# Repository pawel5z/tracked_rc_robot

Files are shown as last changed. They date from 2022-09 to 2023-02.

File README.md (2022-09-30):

# tracked_rc_robot

Tracked robot prototype with bluetooth remote control, using [Dabble app](https://thestempedia.com/docs/dabble/game-pad-module/)'s gamepad module.



## Demo

demo_thumbnail (https://youtu.be/WPtYzlPSiFU)

## Components

* [Black Gladiator - Tracked Robot Chassis](https://www.dfrobot.com/product-1860.html)
* Raspberry Pi Pico
* HC-05 bluetooth module
* 2 x L293D motor driver
* L7805 voltage regulator
* tact switch 6x6mm THT
* 2 x capacitor 1µF
* 3 x capacitor 100nF
* capacitor 330nF
* 2 x Li-ion 18650 3.7V 2200mAh cell

## Notes

[Board layout](https://github.com/pawel5z/tracked_rc_robot/blob/main/circuit/stripboard.diy) created with [DIY Layout Creator](http://diy-fever.com/software/diylc/).



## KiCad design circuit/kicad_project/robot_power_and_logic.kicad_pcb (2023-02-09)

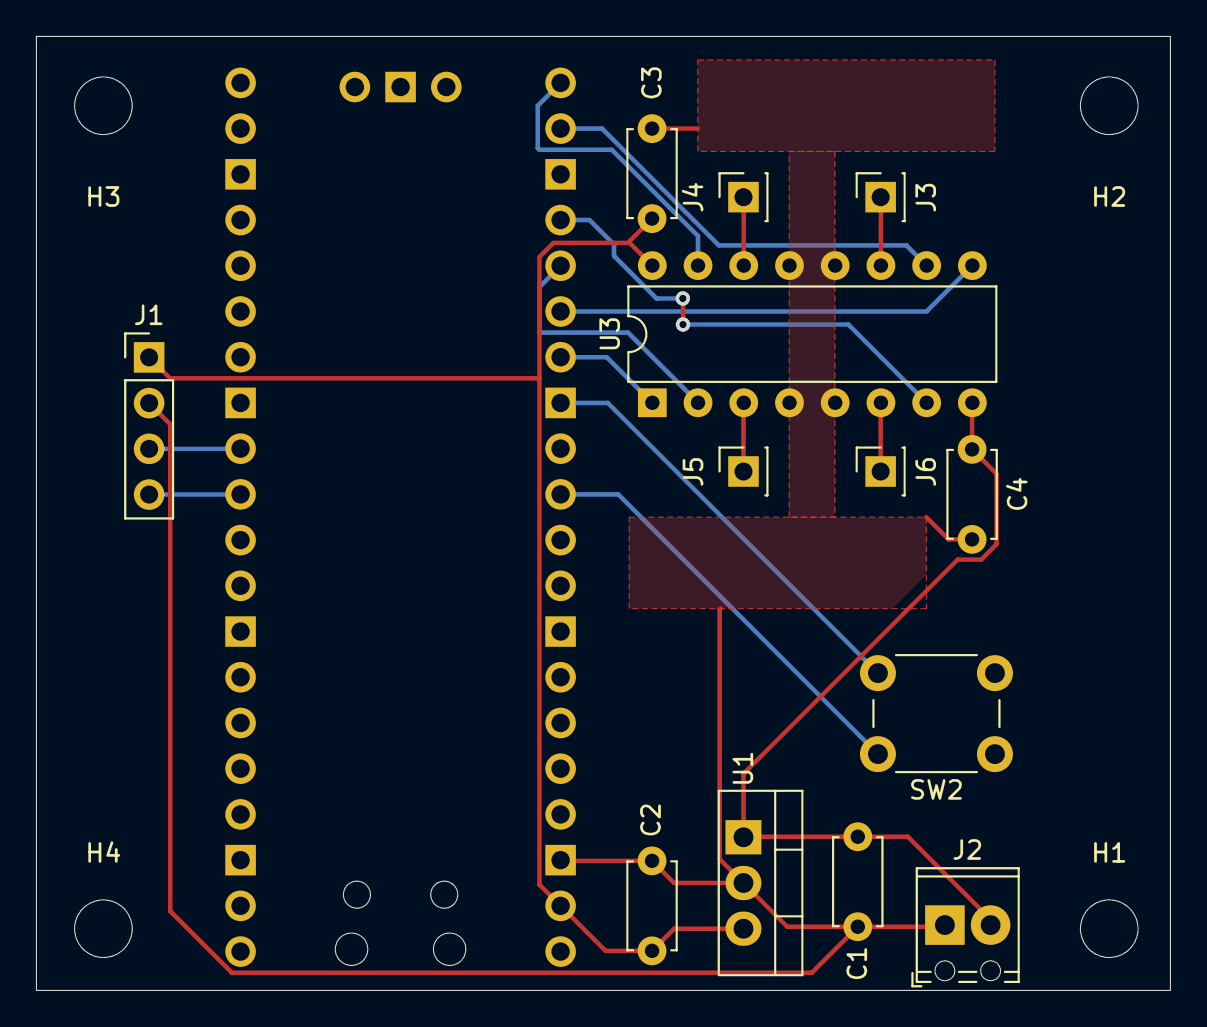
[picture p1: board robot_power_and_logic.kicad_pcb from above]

Board: 2 copper layers, 63.0 x 53.0 mm, 18 parts (1 on the bottom side), 17 nets.

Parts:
C1: 330 nF; C_Disc_D4.7mm_W2.5mm_P5.00mm
C2, C3: 100 nF; C_Disc_D4.7mm_W2.5mm_P5.00mm
C4: 1 µF; C_Disc_D4.7mm_W2.5mm_P5.00mm
H1, H2, H3, H4: MountingHole; MountingHole_3.2mm_M3
J1: HC-05 connection socket; PinHeader_1x04_P2.54mm_Vertical
J2: Power terminal; TerminalBlock_Phoenix_MPT-0,5-2-2.54_1x02_P2.54mm_Horizontal
J3: right_track_motor+; PinSocket_1x01_P2.54mm_Vertical
J4: right_track_motor-; PinSocket_1x01_P2.54mm_Vertical
J5: left_track_motor+; PinSocket_1x01_P2.54mm_Vertical
J6: left_track_motor-; PinSocket_1x01_P2.54mm_Vertical
SW2: Reset; SW_PUSH_6mm_H4.3mm
U1: LM7805_TO220; TO-220-3_Vertical
U2: Pico; RPi_Pico_SMD_TH
U3: L293D; DIP-16_W7.62mm

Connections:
/+5V: C2.1, C3.2, J1.1, U1.3 (VO), U2.39 (VSYS), U3.16 (VCC1)
/+7.4V: C1.1, C4.2, J2.2, U1.1 (VI), U3.8 (VCC2)
/GND: C1.2, C2.2, C3.1, C4.1, J1.2, J2.1, U1.2 (GND), U2.38 (GND), U3.4 (GND), U3.5 (GND), U3.12 (GND), U3.13 (GND)
/HC-05 RX: J1.4, U2.11 (GPIO8)
/HC-05 TX: J1.3, U2.12 (GPIO9)
/left_track_motor_ch_in_1: U2.25 (GPIO19), U3.2 (1A)
/left_track_motor_ch_in_2: U2.24 (GPIO18), U3.7 (2A)
/left_track_motor_en: U2.27 (GPIO21), U3.1 (EN1,2)
/right_track_motor_ch_in_1: U2.22 (GPIO17), U3.10 (3A)
/right_track_motor_ch_in_2: U2.21 (GPIO16), U3.15 (4A)
/right_track_motor_en: U2.26 (GPIO20), U3.9 (EN3,4)
unnamed: J3.1, U3.11 (3Y)
unnamed: J4.1, U3.14 (4Y)
unnamed: J5.1, U3.3 (1Y)
unnamed: J6.1, U3.6 (2Y)
unnamed: SW2.1, U2.30 (RUN)
unnamed: SW2.2, U2.28 (GND)

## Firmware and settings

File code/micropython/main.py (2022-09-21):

from machine import Pin, PWM, UART


class Track:
    """Class controlling a track with pair of L293 channels.
    """
    MAX_DUTY_CYCLE = 65535

    def __init__(self, enable: int, channels, freq: int, lowest_spin_duty: int = 0):
        """Initialize Track object.

        Args:
            enable (PWM): Pin number with PWM capability.
            channels (List[int]): List of two pin numbers connected to L293 channels.
            The first one refers to forward channel, the second one to backward.
            freq (int): PWM frequency.
            lowest_spin_duty (int): Integer in range 0 to 65535.
            The lowest duty cycle making track spin. Defaults to None.

        Raises:
            ValueError: If given incorrect argument.
        """
        self.enable = PWM(Pin(enable))
        self.enable.freq(freq)
        self.enable.duty_u16(0)
        if len(channels) != 2:
            raise ValueError(f"Incorrent number of channels: {2}.")
        self.channels = [Pin(channels[0], Pin.OUT), Pin(channels[1], Pin.OUT)]
        if lowest_spin_duty < 0 or lowest_spin_duty > 65535:
            raise ValueError(
                f"Incorrect lowest_spin_duty value: {lowest_spin_duty}.")
        self.lowest_spin_duty = lowest_spin_duty

    def set_power(self, power: float):
        """Set track's power in range [0, 100]%.

        Args:
            duty (float): Number in range [0, 100].
        """
        self.enable.duty_u16(0 if not power else int(
            self.lowest_spin_duty + power / 100 * (Track.MAX_DUTY_CYCLE - self.lowest_spin_duty)))

    def fast_stop(self):
        """Brake the track.
        """
        self.set_power(100)
        for chan in self.channels:
            chan(0)

    def forward(self, power: float = None):
        """Rotate track forward.

        Args:
            power (float, optional): Optional track's power to set. Defaults to None.
        """
        self.channels[0](1)
        self.channels[1](0)
        if power is not None:
            self.set_power(power)

    def backward(self, power: float = None):
        """Rotate track backward.

        Args:
            power (float, optional): Optional track's power to set. Defaults to None.
        """
        self.channels[0](0)
        self.channels[1](1)
        if power is not None:
            self.set_power(power)


class DabbleGamepad:
    """Class containing Dabble gamepad specific values and methods.
    https://thestempedia.com/docs/dabble/game-pad-module/
    """
    GAMEPAD_MAGIC = b'\xff\x01\x02\x01\x02'

    START = 0x1
    SELECT = 0x2
    CROSS = 0x10
    TRIANGLE = 0x04
    CIRCLE = 0x08
    SQUARE = 0x20

    DIRS_CNT = 24
    DIRS_IN_QT_CNT = 7
    ZERO_ANGLE = 0
    DEG_0 = ZERO_ANGLE
    RIGHT_ANGLE = 6
    DEG_90 = RIGHT_ANGLE
    STRAIGHT_ANGLE = 12
    DEG_180 = STRAIGHT_ANGLE
    DEG_270 = 18
    FULL_ANGLE = 0
    DEG_360 = 0

    RIGHT_ANGLE_OFFSET = 6

    MAX_RADIUS = 7
    RADIUS_MASK = 0b111
    DIR_MASK = ~RADIUS_MASK

    @staticmethod
    def get_joystick_radius(joystick: int) -> int:
        """Get radius from joystick byte of the packet.

        Args:
            joystick (int): Joystick byte of the packet.

        Returns:
            int: Radius input.
        """
        return joystick & DabbleGamepad.RADIUS_MASK

    @staticmethod
    def get_joystick_dir(joystick: int) -> int:
        """Get direction from joystick byte of the packet.

        Args:
            joystick (int): Joystick byte of the packet.

        Returns:
            int: Number coding direction. From 0 to 23. 15-degree parts of 360 degree angle measured counter-clockwise from right.
        """
        return (joystick & DabbleGamepad.DIR_MASK) >> 3


def handle_button(button: int, track_left: Track, track_right: Track):
    """Handle button press.

    Args:
        button (int): Button bitmask.
        track_left (Track): Left track.
        track_right (Track): Right track.
    """
    if button & DabbleGamepad.SQUARE:
        track_left.fast_stop()
        track_right.fast_stop()


def handle_joystick(joystick: int, track_left: Track, track_right: Track):
    """Handle joystick input.

    Args:
        joystick (int): Joystick byte of the packet.
        track_left (Track): Left track.
        track_right (Track): Right track.
    """
    radius = DabbleGamepad.get_joystick_radius(joystick)
    if radius == 0:
        track_left.set_power(0)
        track_right.set_power(0)
        return

    direction = DabbleGamepad.get_joystick_dir(joystick)

    left_power = 100
    if direction >= DabbleGamepad.DEG_90 and direction < DabbleGamepad.DEG_180:
        track_left.forward()
        left_power *= (DabbleGamepad.DEG_180 - direction) / \
            DabbleGamepad.RIGHT_ANGLE_OFFSET
    elif direction <= DabbleGamepad.DEG_270 and direction > DabbleGamepad.DEG_180:
        track_left.backward()
        left_power *= (direction - DabbleGamepad.DEG_180) / \
            DabbleGamepad.RIGHT_ANGLE_OFFSET
    elif direction == DabbleGamepad.DEG_180:
        track_left.backward()
    elif direction < DabbleGamepad.DEG_90:
        track_left.forward()
    elif direction > DabbleGamepad.DEG_270:
        track_left.backward()

    right_power = 100
    if direction <= DabbleGamepad.DEG_90 and direction > 0:
        track_right.forward()
        right_power *= direction / DabbleGamepad.RIGHT_ANGLE_OFFSET
    elif direction >= DabbleGamepad.DEG_270:
        track_right.backward()
        right_power *= (DabbleGamepad.DIRS_CNT - direction) / \
            DabbleGamepad.RIGHT_ANGLE_OFFSET
    elif direction == DabbleGamepad.DEG_0:
        track_right.backward()
    elif direction <= DabbleGamepad.DEG_180:
        track_right.forward()
    elif direction < DabbleGamepad.DEG_270:
        track_right.backward()

    radius_mul = radius / DabbleGamepad.MAX_RADIUS
    track_left.set_power(left_power * radius_mul)
    track_right.set_power(right_power * radius_mul)


led = Pin(25, Pin.OUT, value=1)
led(1)

TRACK_MOTOR_PWM_FREQ = 5000
LOWEST_SPIN_DUTY = 44032
track_left = Track(21, [19, 18], TRACK_MOTOR_PWM_FREQ, LOWEST_SPIN_DUTY)
track_right = Track(20, [17, 16], TRACK_MOTOR_PWM_FREQ, LOWEST_SPIN_DUTY)

bt_uart = UART(1, baudrate=9600, tx=Pin(8), rx=Pin(9),
               timeout=1000)

packet = bytes()
while True:
    byte = bt_uart.read(1)
    if byte == b'\x00' and len(packet) == 7 and packet[:5] == DabbleGamepad.GAMEPAD_MAGIC:
        handle_joystick(packet[6], track_left, track_right)
        handle_button(packet[5], track_left, track_right)
        packet = bytes()
    elif byte is not None:
        packet = (packet + byte)[-7:]

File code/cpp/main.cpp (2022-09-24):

#include "dabble.h"
#include "track.h"

#include "hardware/uart.h"

#include "pico/stdlib.h"

#include <deque>

/**
 * @brief Handle button press.
 *
 * @param button Button bitmask.
 * @param trackLeft
 * @param trackRight
 */
void handleButton(char button, Track &trackLeft, Track &trackRight) {
    if (button & dabble_gamepad::square) {
        trackLeft.brake();
        trackRight.brake();
    }
}

/**
 * @brief Handle joystick input.
 *
 * @param joystick
 * @param trackLeft
 * @param trackRight
 */
void handleJoystick(char joystick, Track &trackLeft, Track &trackRight) {
    int radius = dabble_gamepad::getJoystickRadius(joystick);
    if (radius == 0) {
        trackLeft.setPower(0);
        trackRight.setPower(0);
        return;
    }

    int direction = dabble_gamepad::getJoystickDir(joystick);

    float leftPower = 100;
    if (direction >= dabble_gamepad::deg90 && direction < dabble_gamepad::deg180) { // up, up/left
        trackLeft.forward();
        leftPower *= (dabble_gamepad::deg180 - direction) / float(dabble_gamepad::rightAngleOffset);
    } else if (direction <= dabble_gamepad::deg270 &&
               direction > dabble_gamepad::deg180) { // down, down/left
        trackLeft.backward();
        leftPower *= (direction - dabble_gamepad::deg180) / float(dabble_gamepad::rightAngleOffset);
    } else if (direction == dabble_gamepad::deg180) // left
        trackLeft.backward();
    else if (direction < dabble_gamepad::deg90) // up/right, right
        trackLeft.forward();
    else if (direction > dabble_gamepad::deg270) // down/right
        trackLeft.backward();

    float rightPower = 100;
    if (direction <= dabble_gamepad::deg90 and direction > 0) { // up, up/right
        trackRight.forward();
        rightPower *= direction / float(dabble_gamepad::rightAngleOffset);
    } else if (direction >= dabble_gamepad::deg270) { // down, down/right
        trackRight.backward();
        rightPower *=
            (dabble_gamepad::dirsCnt - direction) / float(dabble_gamepad::rightAngleOffset);
    } else if (direction == dabble_gamepad::deg0) // right
        trackRight.backward();
    else if (direction <= dabble_gamepad::deg180) // left, up/left
        trackRight.forward();
    else if (direction < dabble_gamepad::deg270) // down/left
        trackRight.backward();

    float radiusMul = radius / float(dabble_gamepad::maxRadius);
    trackLeft.setPower(leftPower * radiusMul);
    trackRight.setPower(rightPower * radiusMul);
}

int main() {
    // Set on-board led to constant flashing.
    gpio_init(PICO_DEFAULT_LED_PIN);
    gpio_set_dir(PICO_DEFAULT_LED_PIN, GPIO_OUT);
    gpio_put(PICO_DEFAULT_LED_PIN, 1);

    // Set up tracks' controls.
    const int trackMotorPwmFreq = 5000; // Maximum recommended frequency for L293.
    const int lowestSpinDuty = 832;     // Obtained from testing.
    Track trackLeft(21, {19, 18}, trackMotorPwmFreq, lowestSpinDuty);
    Track trackRight(20, {17, 16}, trackMotorPwmFreq, lowestSpinDuty);

    // Set up UART communication with bluetooth module.
#define BT_UART uart1
#define BT_UART_TX_PIN 8
#define BT_UART_RX_PIN 9
    uart_init(BT_UART, 9600);
    uart_set_format(BT_UART, 8, 1, UART_PARITY_NONE);
    gpio_set_function(BT_UART_TX_PIN, GPIO_FUNC_UART);
    gpio_set_function(BT_UART_RX_PIN, GPIO_FUNC_UART);

    std::deque<char> packet;

    while (true) {
        char byte = uart_getc(BT_UART);

        if (byte == 0x00 && packet.size() == 7 &&
            std::deque<char>(packet.begin(), packet.begin() + 5) ==
                dabble_gamepad::joystickGamepadMagic) {
            handleJoystick(packet.at(6), trackLeft, trackRight);
            handleButton(packet.at(5), trackLeft, trackRight);
        }

        packet.push_back(byte);
        if (packet.size() == 8)
            packet.pop_front();
    }
}

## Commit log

2022-08-31 Add circuit diagram and notes
    [robot_power_and_logic.kicad_sch]
2022-08-31 Add 2nd motor driver
    [robot_power_and_logic.kicad_sch]
2022-08-31 Remove previous circuit diagrams
    cause we have version control for keeping them.
    [robot_power_and_logic.kicad_sch]
2022-08-31 Add bypass capacitors to motor drivers
    [robot_power_and_logic.kicad_sch]
2022-08-31 Add HC-05 pinout
    [robot_power_and_logic.kicad_sch]
2022-09-01 Update HC-05 power connection
    [robot_power_and_logic.kicad_sch]
2022-09-01 Move circuit diagram files to separate directory
    [robot_power_and_logic.kicad_sch]
2022-09-01 Change UART pins used for communication with HC-05
    [robot_power_and_logic.kicad_sch]
2022-09-01 Add stripboard circuit diagram
2022-09-02 Add trace cuts under motor drivers
2022-09-04 Add steering logic
2022-09-15 Fix joystick input interpretation
    [main.py]
2022-09-17 Fix `None` value access in `Track` class
    [main.py]
2022-09-21 Simplify `Track`'s power implementation
2022-09-22 Add `pico-sdk` submodule
2022-09-24 Add docstrings
    and choose more descriptive name for bluetooth UART.
2022-09-24 Fix PWM setup and control
    [main.cpp, track.cpp]
2022-09-26 Fix docstring of `Track` class
2022-09-30 Update board layout schematic
2022-09-30 Add board layout details to `README.md`
2023-02-05 Replace some wire connections with label connections
    [robot_power_and_logic.kicad_sch]
2023-02-05 Assign some footprints and add no-connection flags
    [robot_power_and_logic.kicad_sch]
2023-02-05 Add power symbols
    [robot_power_and_logic.kicad_sch]
2023-02-05 Align elements
    [robot_power_and_logic.kicad_sch]
2023-02-07 Assign capacitor footprints
    [robot_power_and_logic.kicad_sch]
2023-02-07 Add title, date and revision number
    [robot_power_and_logic.kicad_sch]
2023-02-07 Add L293D soldering info
    [robot_power_and_logic.kicad_sch]
2023-02-08 Replace spst reset switch with push button switch
    [robot_power_and_logic.kicad_sch]
2023-02-08 Fix Raspberry Pi Pico symbol
    [robot_power_and_logic.kicad_sch]
2023-02-08 Update reset button footprint
    [robot_power_and_logic.kicad_sch]
2023-02-08 Assign correct footprint to Raspberry Pi Pico
    [robot_power_and_logic.kicad_sch]
2023-02-08 Clean up power annotations
    [robot_power_and_logic.kicad_sch]
2023-02-08 Add screw terminal
    [robot_power_and_logic.kicad_sch]
2023-02-08 Add mounting holes and swap pins of screw terminal
    [robot_power_and_logic.kicad_sch]
2023-02-08 Replace some GND symbols with GND labels
    [robot_power_and_logic.kicad_sch]
2023-02-09 Replace motors with their connection sockets
    [robot_power_and_logic.kicad_sch]
2023-02-09 Update power source connection description
    [robot_power_and_logic.kicad_sch]
2023-02-09 Remove one L293D driver
    [robot_power_and_logic.kicad_sch]
2023-02-09 Create empty PCB design
    [robot_power_and_logic.kicad_pcb]
2023-02-09 Create PCB elements layout
    [robot_power_and_logic.kicad_pcb]
2023-02-09 Add routes to PCB design
    [robot_power_and_logic.kicad_pcb]
